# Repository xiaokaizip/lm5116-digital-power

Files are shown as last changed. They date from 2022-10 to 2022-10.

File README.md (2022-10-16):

### lm5116数控可调电源

- 输入电压：24V的学生电源

- 目标输出电压：5V-12V
- 目标输出电流：（越大越好）
- 使用0.96寸oled屏显示电压值

### 电路

#### 一、控制器件

- 主要的电压控制器件还是lm5116
- 其中的stm32f103c8t6还是起到辅助的作用。
  - 控制数字电位器的电阻大小
  - 采集电压
  - 接收按键的输入
  - 控制屏幕的显示内容

#### 二、输出电压的调节

- 使用数字电位器调节反馈端的电压，一次来改变输出电压的大小。

#### 三、数据采集

- 使用ADC将电压采集到单片机。
- 再实时数据通过串口传到电脑

#### 四、控制

- 使用按键进行操作。

#### 五、辅助电源

- 使用TD1469将24V的输入降至5V，在使用HX9193将5V的电压降至3.3V个stm32 、数字电位器供电、屏幕供电。

### 代码

#### 一、数字电位器（MCP41100）

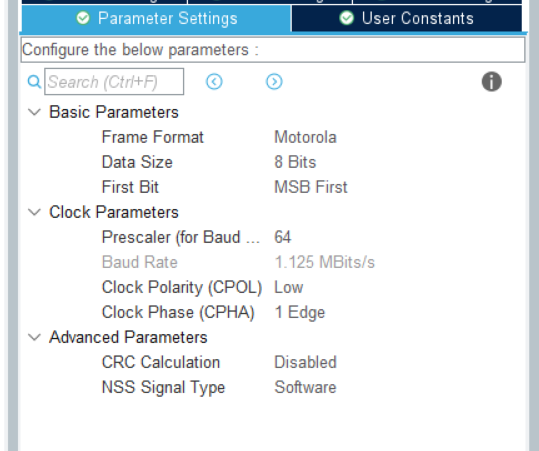
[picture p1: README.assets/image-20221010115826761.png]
- 数字电位器的配置如图所示：

没有用到DMA或是中断，需要的话后续再来给他加上。

- 使能数字电位器

  ~~~c
  #define MCP41100_ENABLE     0B00010011
  #define MCP41100_DISABLE    0B00100000
  ~~~

- 调节数字电位器

  - 数字电位器将100k$\Omega$的电阻分成256份，在使用时，只需将其换算即可。

- 代码

~~~c
uint8_t command;
uint8_t data;

void MCP41100_Send_Data(uint8_t commands, uint8_t datas) {
    HAL_GPIO_WritePin(GPIOA, GPIO_PIN_4, GPIO_PIN_RESET);//来低数字电位器的CS引脚，开始准备通讯
    HAL_Delay(0);
    HAL_SPI_Transmit(&hspi1, &command, 1, 0xffff);//传送命令字节
    HAL_SPI_Transmit(&hspi1, &data, 1, 0xffff);//传送数据字节
    HAL_Delay(0);
    HAL_GPIO_WritePin(GPIOA, GPIO_PIN_4, GPIO_PIN_SET);//将CS引脚拉高，关闭通讯
}

~~~

==相应的文件以放在divice-library文件夹中==

#### 二、延时函数

==相应的文件以放在divice-library文件夹中==

#### 三、OLED屏

- 在此次的项目中，使用了软件iic。

- 其中OLED屏的驱动也是从别处搬来的，后续咋来研究是怎么写的。

- 相关的函数说明

~~~c
 OLED_Init();	//初始化OLED
 OLED_Fill(0x00);//清屏
 OLED_ShowStr(0, 0, "hell world");//在指定位置显示字符串
 OLED_ShowFloat(0,0,123.456f);//在指定的位置显示浮点数（小数点后三位）
~~~

==相应的文件以放在divice-library文件夹中==

#### 四、 数据类型转化

- 将浮点数转化为字符串

~~~c

void numTostring(float num, char str[10]) {

    char ch[10];
    int i = 0;//跟随ch
    int j = 0;//跟随str
    //判断是否是负数
    if (num < 0) {
        num = -num;
        str[j++] = '-';

    }
    //判断是否是小数，如果是小数，先加上0；
    if (num < 1) {
        str[j++] = '0';

    }
    //将小数乘上1000，意味着将该数字精确到小数点后三位，要改精度就改一下1000这个数字就行
    num *= 1000;
    int nums = (int) num;//将小数转换为整数
    for (i = 8; i >= 0; i--) {
        if (i == 5) {
            ch[i] = '.';
            i--;
        }
        ch[i] = nums % 10 + '0';
        nums /= 10;
    }
    //加上小数点
    ch[9] = '\0';
    i = 0;
    while (ch[i] == '0') {
        i++;
    }
    for (i; i <= 9; i++) {
        str[j] = ch[i];
        j++;
    }
}
~~~

==相应的文件以放在divice-library文件夹中==

- 该转换方式还是有点过于复杂，后续还需学习更加方便的转换方法。

#### 五、ADC电压采样

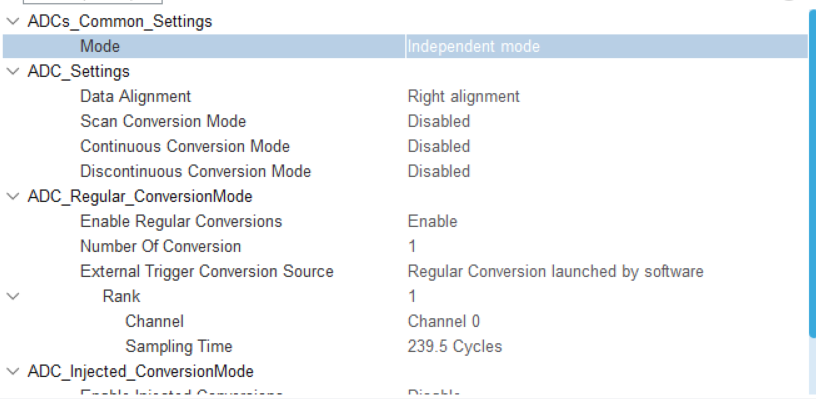
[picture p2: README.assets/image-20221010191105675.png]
- ADC的简单配置如下：
  - **Data Alignment**：选则有对齐
  - **Scan Conversion Mode：**此项选择扫描模式使能，代表15路ADC输入分别扫描，如果不使能，其只会读取一个输入的值。
  - **Contionous Conversion Mode:**此项选择连续扫描模式，表示将连续不断的对ADC的值进行转换，如果此项不使能，将会只采集一次就停止，直到下一次使能才继续进行一次AD转换。
  - **DisContionous Conversion Mode:**此项与第三项重复。
  - **Number of Conversion：**此处有多少路输出就选择多少。
  - **Rank：**采样时间。
- DMA的配置

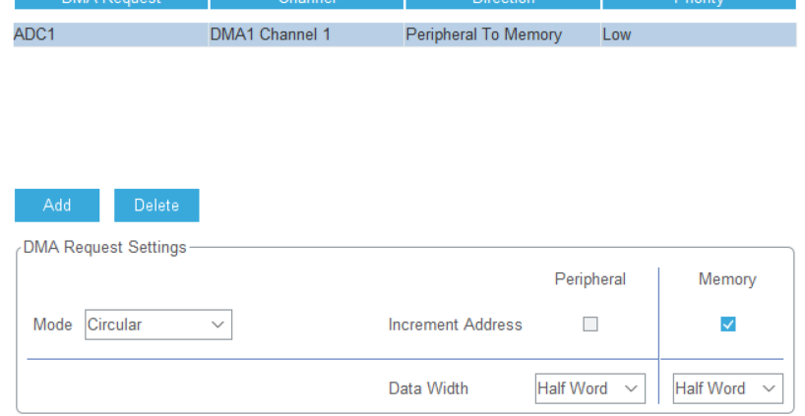
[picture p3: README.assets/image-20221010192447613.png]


- 代码

~~~c
HAL_ADC_Start_DMA(&hadc1, (uint32_t *) adc_value, 1);
//使能DMA，adc_value 为存储数据的数组，1为每一次采样的次数（该数组的大小）
~~~

~~~c
HAL_ADC_Stop_DMA(&hadc1);//失能DMA
~~~

- ADC采样时，如果想要同时采集多个电压，需要打开中断，然后再ADC中断函数中处理数据。

~~~c
void HAL_ADC_ConvCpltCallback();
~~~

可在此函数中，对采集到的电压进行数据处理。

~~~c
void HAL_ADC_ConvCpltCallback(ADC_HandleTypeDef *hadc) {
    uint32_t sum = 0;
    for (uint8_t i = 0; i < 40; i++) {
        sum += adc_value[i];
    }
    avgerage_voltage = (float) sum / 40.0f;
    avgerage_voltage = avgerage_voltage * 0.2f + last_voltage * 0.8f;
    last_voltage = avgerage_voltage;
    flag = 1;
}
~~~

#### 六、按键处理

- 消抖

~~~c
if (HAL_GPIO_ReadPin(GPIOB, GPIO_PIN_12) == GPIO_PIN_RESET) {
        HAL_Delay(10);
        while (HAL_GPIO_ReadPin(GPIOB, GPIO_PIN_12) == GPIO_PIN_RESET);
        HAL_Delay(10);
        flag = RESISTANCE_UP;
    } 
~~~

### 问题

- 该板子是一个可调压的buck电路，输入电压为24V，输出电压为5V至12V
- 可通过stm32f103c6t6，控制数字电位器，以此来控制输出电压。

- 该板子函数有一点问题
 - 按键的设置没设置好。
 - 比如lm5116发烫有点严重，可能是参数还没调好。
 - 采样的滤波还没写好。
 - ……

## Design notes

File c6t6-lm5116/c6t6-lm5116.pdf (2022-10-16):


10/10/2022

c6t6-lm5116 Project
Configuration Report

## 1. Description

### 1.1. Project

Project Name | c6t6-lm5116
Board Name | custom
Generated with: | STM32CubeMX 6.6.1
Date | 10/10/2022

### 1.2. MCU

MCU Series | STM32F1
MCU Line | STM32F103
MCU name | STM32F103C6Tx
MCU Package | LQFP48
MCU Pin number | 48

### 1.3. Core(s) information

Core(s) | Arm Cortex-M3

## 2. Pinout Configuration

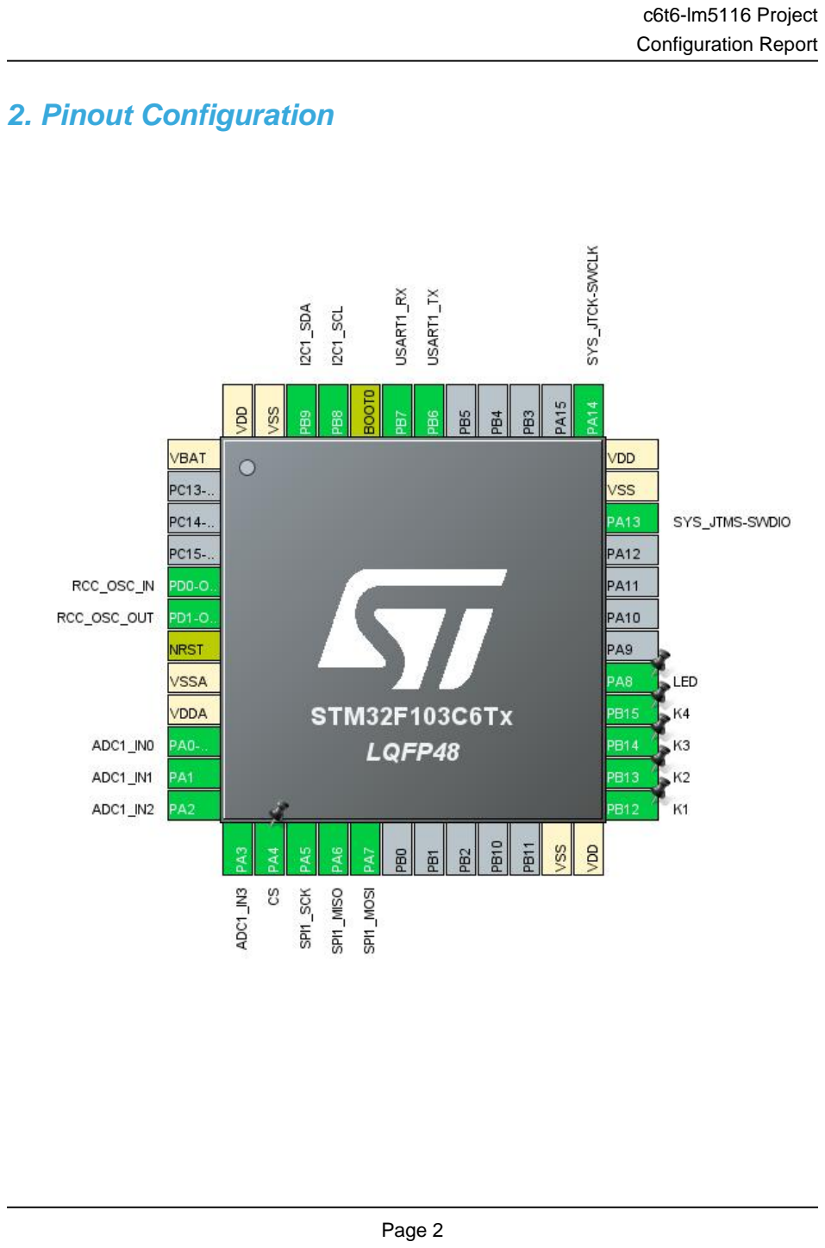
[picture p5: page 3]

## 3. Pins Configuration

Pin Number LQFP48 | Pin Name (function after reset) | Pin Type | Alternate Function(s) | Label
1 | VBAT | Power
5 | PD0-OSC_IN | I/O | RCC_OSC_IN
6 | PD1-OSC_OUT | I/O | RCC_OSC_OUT
7 | NRST | Reset
8 | VSSA | Power
9 | VDDA | Power
10 | PA0-WKUP | I/O | ADC1_IN0
11 | PA1 | I/O | ADC1_IN1
12 | PA2 | I/O | ADC1_IN2
13 | PA3 | I/O | ADC1_IN3
14 | PA4 * | I/O | GPIO_Output | CS
15 | PA5 | I/O | SPI1_SCK
16 | PA6 | I/O | SPI1_MISO
17 | PA7 | I/O | SPI1_MOSI
23 | VSS | Power
24 | VDD | Power
25 | PB12 * | I/O | GPIO_Input | K1
26 | PB13 * | I/O | GPIO_Input | K2
27 | PB14 * | I/O | GPIO_Input | K3
28 | PB15 * | I/O | GPIO_Input | K4
29 | PA8 * | I/O | GPIO_Output | LED
34 | PA13 | I/O | SYS_JTMS-SWDIO
35 | VSS | Power
36 | VDD | Power
37 | PA14 | I/O | SYS_JTCK-SWCLK
42 | PB6 | I/O | USART1_TX
43 | PB7 | I/O | USART1_RX
44 | BOOT0 | Boot
45 | PB8 | I/O | I2C1_SCL
46 | PB9 | I/O | I2C1_SDA
47 | VSS | Power
48 | VDD | Power

* The pin is affected with an I/O function

## 4. Clock Tree Configuration

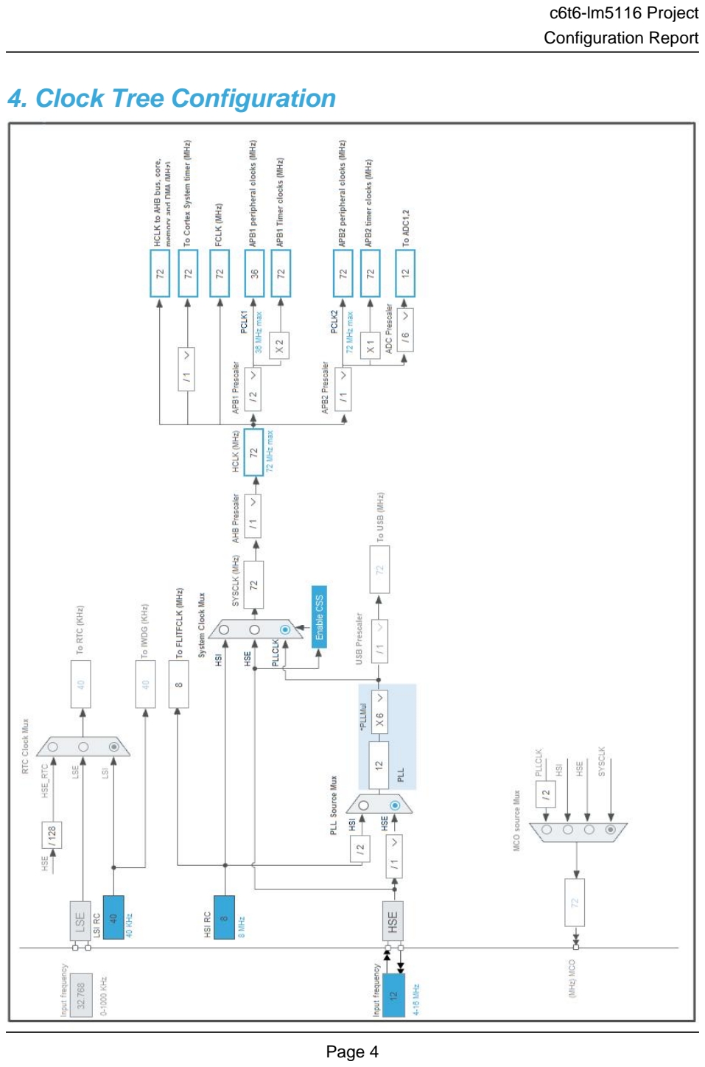
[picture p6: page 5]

## 5. Software Project

### 5.1. Project Settings

Name | Value
Project Name | c6t6-lm5116
Project Folder | D:\stm32 project\c6t6-lm5116
Toolchain / IDE | STM32CubeIDE
Firmware Package Name and Version | STM32Cube FW_F1 V1.8.4
Application Structure | Advanced
Generate Under Root | Yes
Do not generate the main() | No
Minimum Heap Size | 0x200
Minimum Stack Size | 0x400

### 5.2. Code Generation Settings

Name | Value
STM32Cube MCU packages and embedded software | Copy only the necessary library files
Generate peripheral initialization as a pair of '.c/.h' files | Yes
Backup previously generated files when re-generating | No
Keep User Code when re-generating | Yes
Delete previously generated files when not re-generated | Yes
Set all free pins as analog (to optimize the power consumption) | No
Enable Full Assert | No

### 5.3. Advanced Settings - Generated Function Calls

Rank | Function Name | Peripheral Instance Name
1 | SystemClock_Config | RCC
2 | MX_GPIO_Init | GPIO
3 | MX_ADC1_Init | ADC1
4 | MX_I2C1_Init | I2C1
5 | MX_SPI1_Init | SPI1
6 | MX_USART1_UART_Init | USART1

## 6. Power Consumption Calculator report

### 6.1. Microcontroller Selection

Series | STM32F1
Line | STM32F103
MCU | STM32F103C6Tx
Datasheet | DS5936_Rev7

### 6.2. Parameter Selection

Temperature | 25
Vdd | 3.3

### 6.3. Battery Selection

Battery | Li-SOCL2(A3400)
Capacity | 3400.0 mAh
Self Discharge | 0.08 %/month
Nominal Voltage | 3.6 V
Max Cont Current | 100.0 mA
Max Pulse Current | 200.0 mA
Cells in series | 1
Cells in parallel | 1

### 6.4. Sequence

Step | Step1 | Step2
Mode | RUN | STOP
Vdd | 3.3 | 3.3
Voltage Source | Battery | Battery
Range | No Scale | No Scale
Fetch Type | FLASH | n/a
CPU Frequency | 72 MHz | 0 Hz
Clock Configuration | HSE PLL | Regulator_LP
Clock Source Frequency | 8 MHz | 0 Hz
Peripherals
Additional Cons. | 0 mA | 0 mA
Average Current | 24.5 mA | 11.7 µA
Duration | 0.1 ms | 0.9 ms
DMIPS | 90.0 | 0.0
Ta Max | 100.55 | 105
Category | In DS Table | In DS Table

### 6.5. Results

Sequence Time | 1 ms | Average Current | 2.46 mA
Battery Life | 1 month, 27 days, 1 hour | Average DMIPS | 61.0 DMIPS

### 6.6. Chart

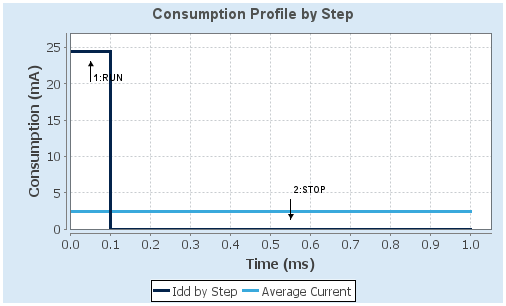
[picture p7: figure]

## 7. Peripherals and Middlewares Configuration

### 7.1. ADC1

mode: IN0
mode: IN1
mode: IN2
mode: IN3
7.1.1. Parameter Settings:

ADCs_Common_Settings:

Mode | Independent mode
ADC_Settings:
Data Alignment | Right alignment
Scan Conversion Mode | Disabled
Continuous Conversion Mode | Disabled
Discontinuous Conversion Mode | Disabled
ADC_Regular_ConversionMode:
Enable Regular Conversions | Enable
Number Of Conversion | 1
External Trigger Conversion Source | Regular Conversion launched by software
Rank | 1
Channel | Channel 0
Sampling Time | 1.5 Cycles
ADC_Injected_ConversionMode:
Enable Injected Conversions | Disable
WatchDog:
Enable Analog WatchDog Mode | false

### 7.2. I2C1

I2C: I2C
7.2.1. Parameter Settings:

Master Features:

I2C Speed Mode | Standard Mode
I2C Clock Speed (Hz) | 100000
Slave Features:
Clock No Stretch Mode | Disabled
Primary Address Length selection | 7-bit

Dual Address Acknowledged | Disabled
Primary slave address | 0
General Call address detection | Disabled

### 7.3. RCC

High Speed Clock (HSE): Crystal/Ceramic Resonator
7.3.1. Parameter Settings:

System Parameters:

VDD voltage (V) | 3.3
Prefetch Buffer | Enabled
Flash Latency(WS) | 2 WS (3 CPU cycle)
RCC Parameters:
HSI Calibration Value | 16
HSE Startup Timout Value (ms) | 100
LSE Startup Timout Value (ms) | 5000

### 7.4. SPI1

Mode: Full-Duplex Master
7.4.1. Parameter Settings:

Basic Parameters:

Frame Format | Motorola
Data Size | 8 Bits
First Bit | MSB First
Clock Parameters:
Prescaler (for Baud Rate) | 64 *
Baud Rate | 1.125 MBits/s *
Clock Polarity (CPOL) | Low
Clock Phase (CPHA) | 1 Edge
Advanced Parameters:
CRC Calculation | Disabled
NSS Signal Type | Software

### 7.5. SYS

Debug: Serial Wire
Timebase Source: SysTick

### 7.6. USART1

Mode: Asynchronous
7.6.1. Parameter Settings:

Basic Parameters:

Baud Rate | 115200
Word Length | 8 Bits (including Parity)
Parity | None
Stop Bits | 1
Advanced Parameters:
Data Direction | Receive and Transmit
Over Sampling | 16 Samples

* User modified value

## 8. System Configuration

### 8.1. GPIO configuration

IP | Pin | Signal | GPIO mode | GPIO pull/up pull down | Max Speed | User Label
ADC1 | PA0-WKUP | ADC1_IN0 | Analog mode | n/a | n/a
| PA1 | ADC1_IN1 | Analog mode | n/a | n/a
| PA2 | ADC1_IN2 | Analog mode | n/a | n/a
| PA3 | ADC1_IN3 | Analog mode | n/a | n/a
I2C1 | PB8 | I2C1_SCL | Alternate Function Open Drain | No pull-up and no pull-down | n/a
| PB9 | I2C1_SDA | Alternate Function Open Drain | No pull-up and no pull-down | n/a
RCC | PD0-OSC_IN | RCC_OSC_IN | n/a | n/a | n/a
| PD1-OSC_OUT | RCC_OSC_OUT | n/a | n/a | n/a
SPI1 | PA5 | SPI1_SCK | Alternate Function Push Pull | n/a | High *
| PA6 | SPI1_MISO | Input mode | No pull-up and no pull-down | n/a
| PA7 | SPI1_MOSI | Alternate Function Push Pull | n/a | High *
SYS | PA13 | SYS_JTMS-SWDIO | n/a | n/a | n/a
| PA14 | SYS_JTCK-SWCLK | n/a | n/a | n/a
USART1 | PB6 | USART1_TX | Alternate Function Push Pull | n/a | High *
| PB7 | USART1_RX | Input mode | No pull-up and no pull-down | n/a
GPIO | PA4 | GPIO_Output | Output Push Pull | No pull-up and no pull-down | Low | CS
| PB12 | GPIO_Input | Input mode | No pull-up and no pull-down | n/a | K1
| PB13 | GPIO_Input | Input mode | No pull-up and no pull-down | n/a | K2
| PB14 | GPIO_Input | Input mode | No pull-up and no pull-down | n/a | K3
| PB15 | GPIO_Input | Input mode | No pull-up and no pull-down | n/a | K4
| PA8 | GPIO_Output | Output Push Pull | No pull-up and no pull-down | Low | LED

### 8.2. DMA configuration

nothing configured in DMA service

### 8.3. NVIC configuration

8.3.1. NVIC
Interrupt Table | Enable | Preenmption Priority | SubPriority
Non maskable interrupt | true | 0 | 0
Hard fault interrupt | true | 0 | 0
Memory management fault | true | 0 | 0
Prefetch fault, memory access fault | true | 0 | 0
Undefined instruction or illegal state | true | 0 | 0
System service call via SWI instruction | true | 0 | 0
Debug monitor | true | 0 | 0
Pendable request for system service | true | 0 | 0
System tick timer | true | 15 | 0
PVD interrupt through EXTI line 16 | unused
Flash global interrupt | unused
RCC global interrupt | unused
ADC1 and ADC2 global interrupts | unused
I2C1 event interrupt | unused
I2C1 error interrupt | unused
SPI1 global interrupt | unused
USART1 global interrupt | unused
8.3.2. NVIC Code generation
Enabled interrupt Table | Select for init sequence ordering | Generate IRQ handler | Call HAL handler
Non maskable interrupt | false | true | false
Hard fault interrupt | false | true | false
Memory management fault | false | true | false
Prefetch fault, memory access fault | false | true | false
Undefined instruction or illegal state | false | true | false
System service call via SWI instruction | false | true | false
Debug monitor | false | true | false
Pendable request for system service | false | true | false
System tick timer | false | true | true

* User modified value

## 9. System Views

9.1. Category view
9.1.1. Current

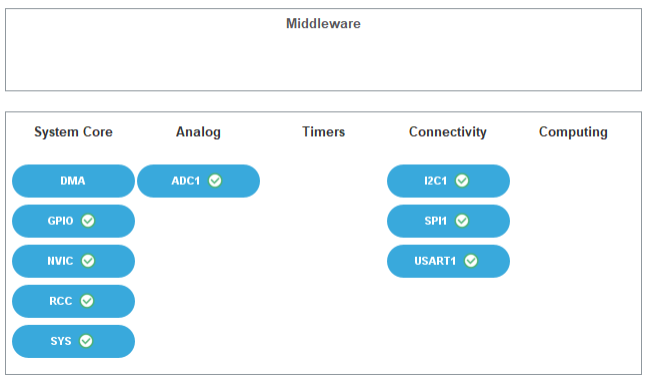
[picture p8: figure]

## 10. Docs & Resources

Type | Link
Presentations | https://www.st.com/resource/en/product_presentation/stm32-stm8_embedded_software_solutions.pdf
Presentations | https://www.st.com/resource/en/product_presentation/stm32_eval-tools_portfolio.pdf
Presentations | https://www.st.com/resource/en/product_presentation/stm32_stm8_functi onal-safety-packages.pdf
Presentations | https://www.st.com/resource/en/product_presentation/stm32-stm8_software_development_tools.pdf
Training Material | https://www.st.com/resource/en/sales_guide/sg_sc2155.pdf
Brochures | https://www.st.com/resource/en/brochure/breveco0518.pdf
Flyers | https://www.st.com/resource/en/flyer/flnucleolrwan.pdf
Flyers | https://www.st.com/resource/en/flyer/flstm32nucleo.pdf
Flyers | https://www.st.com/resource/en/flyer/flstmcsuite.pdf
Flyers | https://www.st.com/resource/en/flyer/fldpstpfc11120.pdf
Product Certifications | https://www.st.com/resource/en/certification_document/1239988349.pdf
Product Certifications | https://www.st.com/resource/en/certification_document/stm32_authentication_can.pdf
Application Notes | https://www.st.com/resource/en/application_note/an1181-electrostatic-discharge-sensitivity-measurement-stmicroelectronics.pdf
Application Notes | https://www.st.com/resource/en/application_note/an1709-emc-design-guide-for-stm8-stm32-and-legacy-mcus-stmicroelectronics.pdf
Application Notes | https://www.st.com/resource/en/application_note/an2548-using-the-stm32f0f1f3gxlx-series-dma-controller-stmicroelectronics.pdf
Application Notes | https://www.st.com/resource/en/application_note/an2586-getting-started-with-stm32f10xxx-hardware-development-stmicroelectronics.pdf
Application Notes | https://www.st.com/resource/en/application_note/an2604-stm32f101xx-and-stm32f103xx-rtc-calibration-stmicroelectronics.pdf
Application Notes | https://www.st.com/resource/en/application_note/an2606-stm32-

| microcontroller-system-memory-boot-mode-stmicroelectronics.pdf
Application Notes | https://www.st.com/resource/en/application_note/an2639-soldering-recommendations-and-package-information-for-leadfree-ecopack-mcus-and-mpus-stmicroelectronics.pdf
Application Notes | https://www.st.com/resource/en/application_note/an2834-how-to-get-the-best-adc-accuracy-in-stm32-microcontrollers-stmicroelectronics.pdf
Application Notes | https://www.st.com/resource/en/application_note/an2945-stm8s-and-stm32-mcus-a-consistent-832bit-product-line-for-painless-migration-stmicroelectronics.pdf
Application Notes | https://www.st.com/resource/en/application_note/an3070-managing-the-driver-enable-signal-for-rs485-and-iolink-communications-with-the-stm32s-usart-stmicroelectronics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
Application Notes | https://www.st.com/resource/en/application_note/an3095-stevalisv002v1-stevalisv002v2-3-kw-gridconnected-pv-system-based-on-the-stm32f103xx-stmicroelectronics.pdf
Application Notes | https://www.st.com/resource/en/application_note/an3108-stlm75-firmware-library-for-the-stm32f10x-stmicroelectronics.pdf
Application Notes | https://www.st.com/resource/en/application_note/an3126-audio-and-waveform-generation-using-the-dac-in-stm32-products-stmicroelectronics.pdf
Application Notes | https://www.st.com/resource/en/application_note/an3128-stm32-embedded-graphic-objectstouchscreen-library-stmicroelectronics.pdf
Application Notes | https://www.st.com/resource/en/application_note/an3154-can-protocol-used-in-the-stm32-bootloader-stmicroelectronics.pdf
Application Notes | https://www.st.com/resource/en/application_note/an3155-usart-protocol-used-in-the-stm32-bootloader-stmicroelectronics.pdf
Application Notes | https://www.st.com/resource/en/application_note/an3156-usb-dfu-protocol-used-in-the-stm32-bootloader-stmicroelectronics.pdf
Application Notes | https://www.st.com/resource/en/application_note/an3364-migration-and-compatibility-guidelines-for-stm32-microcontroller-applications-stmicroelectronics.pdf
Application Notes | https://www.st.com/resource/en/application_note/an3422-migration-of- microcontroller-applications-from-stm32f1-to-stm32l1-series-

| stmicroelectronics.pdf
Application Notes | https://www.st.com/resource/en/application_note/an3427-migrating-a-microcontroller-application-from-stm32f1-to-stm32f2-series-stmicroelectronics.pdf
Application Notes | https://www.st.com/resource/en/application_note/an3429-stm32-proprietary-code-protection-overview-stmicroelectronics.pdf
Application Notes | https://www.st.com/resource/en/application_note/an4013-stm32-crossseries-timer-overview-stmicroelectronics.pdf
Application Notes | https://www.st.com/resource/en/application_note/an4070-250-w-grid-connected-microinverter-stmicroelectronics.pdf
Application Notes | https://www.st.com/resource/en/application_note/an4076-two-or-three-shunt-resistor-based-current-sensing-circuit-design-in-3phase-inverters-stmicroelectronics.pdf
Application Notes | https://www.st.com/resource/en/application_note/an4088-migrating-between-stm32f1-and-stm32f0-series-microcontrollers-stmicroelectronics.pdf
Application Notes | https://www.st.com/resource/en/application_note/an4228-migrating-from-stm32f1-series-to-stm32f3-series-microcontrollers-stmicroelectronics.pdf
Application Notes | https://www.st.com/resource/en/application_note/an4229-how-to-implement-a-vocoder-solution-using-stm32-microcontrollers-stmicroelectronics.pdf
Application Notes | https://www.st.com/resource/en/application_note/an4277-using-stm32-device-pwm-shutdown-features-for-motor-control-and-digital-power-conversion-stmicroelectronics.pdf
Application Notes | https://www.st.com/resource/en/application_note/an4566-extending-the-dac-performance-of-stm32-microcontrollers-stmicroelectronics.pdf
Application Notes | https://www.st.com/resource/en/application_note/an4649-migrating-from-stm32f1-series-to-stm32l4-series--stm32l4-series-microntrollers-stmicroelectronics.pdf
Application Notes | https://www.st.com/resource/en/application_note/an4655-virtually-increasing-the-number-of-serial-communication-peripherals-in-stm32-applications-stmicroelectronics.p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
Application Notes | https://www.st.com/resource/en/application_note/an4724-stm32cube-

| firmware-examples-for-stm32f1-series-stmicroelectronics.pdf
Application Notes | https://www.st.com/resource/en/application_note/an4750-handling-of-soft-errors-in-stm32-applications-stmicroelectronics.pdf
Application Notes | https://www.st.com/resource/en/application_note/an4776-generalpurpose-timer-cookbook-for-stm32-microcontrollers-stmicroelectronics.pdf
Application Notes | https://www.st.com/resource/en/application_note/an4803-highspeed-si-simulations-using-ibis-and-boardlevel-simulations-using-hyperlynx-si-on-stm32-mcus-and-mpus-stmic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
Application Notes | https://www.st.com/resource/en/application_note/an4838-managing-memory-protection-unit-in-stm32-mcus-stmicroelectronics.pdf
Application Notes | https://www.st.com/resource/en/application_note/an4879-usb-hardware-and-pcb-guidelines-using-stm32-mcus-stmicroelectronics.pdf
Application Notes | https://www.st.com/resource/en/application_note/an4904-migration-of-microcontroller-applications-from-stm32f1-series-to-stm32f4-access-lines-stmicroelectronics.pdf
Application Notes | https://www.st.com/resource/en/application_note/an4908-stm32-usart-automatic-baud-rate-detection-stmicroelectronics.pdf
Application Notes | https://www.st.com/resource/en/application_note/an4989-stm32-microcontroller-debug-toolbox-stmicroelectronics.pdf
Application Notes | https://www.st.com/resource/en/application_note/an5027-interfacing-pdm-digital-microphones-using-stm32-mcus-and-mpus-stmicroelectronics.pdf
Application Notes | https://www.st.com/resource/en/application_note/an5036-thermal-management-guidelines-for-stm32-applications-stmicroelectronics.pdf
Application Notes | https://www.st.com/resource/en/application_note/an5156-introduction-to-stm32-microcontrollers-security-stmicroelectronics.pdf
Application Notes | https://www.st.com/resource/en/application_note/an5225-usb-typec-power-delivery-using-stm32-mcus-and-mpus-stmicroelectronics.pdf
Application Notes | https://www.st.com/resource/en/application_note/an5543-enhanced-methods-to-handle-spi-communication-on-stm32-devices-stmicroelectronics.pdf
Application Notes | https://www.st.com/resource/en/application_note/an4899-stm32-microcontroller-gpio-hardware-settings-and-lowpower-consumption-stmicroelectronics.pdf

Application Notes for related Tools & Software | https://www.st.com/resource/en/application_note/an1202_freertos_guide-freertos-guide-stmicroelectronics.pdf
Application Notes for related Tools & Software | https://www.st.com/resource/en/application_note/an1602_semihosting_in_truestudio-how-to-do-semihosting-in-truestudio-stmicroelectronics.pdf
Application Notes for related Tools & Software | https://www.st.com/resource/en/application_note/an1801_stm32cubeprogrammer_in_truestudio-installing-stm32cubeprogrammer-in-truestudio-stmicroelectronics.pdf
Application Notes for related Tools & Software | https://www.st.com/resource/en/application_note/atollic_editing_keyboard_shortcuts-atollic-editing-keyboard-shortcuts-stmicroelectronics.pdf
Application Notes for related Tools & Software | https://www.st.com/resource/en/application_note/iar_to_atollic_truestudio_migration_guide-truestudio-for-arm-migration-guide-iar-embedded-workbench-to-truestudio-stm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
Application Notes for related Tools & Software | https://www.st.com/resource/en/application_note/stm32cubemx_installation_in_truestudio-stm32cubemx-installation-in-truestudio-stmicroelectronics.pdf
Application Notes for related Tools & Software | https://www.st.com/resource/en/application_note/an2557-stm32f10x-inapplication-programming-using-the-usart-stmicroelectronics.pdf
Application Notes for related Tools & Software | https://www.st.com/resource/en/application_note/an2592-achieving-32bit-timer-resolution-with-software-expansion-for-stm32cube-and-standard-peripheral-library-stmicro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
Application Notes for related Tools & Software | https://www.st.com/resource/en/application_note/an2594-eeprom-emulation-in-stm32f10x-microcontrollers-stmicroelectronics.pdf
Application Notes for related Tools & Software | https://www.st.com/resource/en/application_note/an2598-smartcard-interface-with-stm32f10x-and-stm32l1xx-microcontrollers-stmicroelectronics.pdf
Application Notes for related Tools & Software | https://www.st.com/resource/en/application_note/an2629-stm32f101xx-stm32f102xx-and-stm32f103xx-lowpower-modes-stmicroelectronics.pdf
Application Notes | https://www.st.com/resource/en/application_note/an2656-stm32f10xxx-

for related Tools & Software | lcd-glass-driver-firmware-stmicroelectronics.pdf
Application Notes for related Tools & Software | https://www.st.com/resource/en/application_note/an2668-improving-stm32f1-series-stm32f3-series-and-stm32lx-series-adc-resolution-by-oversampling-stmicroelectronics.p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
Application Notes for related Tools & Software | https://www.st.com/resource/en/application_note/an2739-how-to-use-the-highdensity-stm32f103xx-microcontroller-to-play-audio-files-with-an-external-is-audio-codec-stm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
Application Notes for related Tools & Software | https://www.st.com/resource/en/application_note/an2784-using-the-highdensity-stm32f10xxx-fsmc-peripheral-to-drive-external-memories-stmicroelectronics.pdf
Application Notes for related Tools & Software | https://www.st.com/resource/en/application_note/an2790-tft-lcd-interfacing-with-the-highdensity-stm32f10xxx-fsmc-stmicroelectronics.pdf
Application Notes for related Tools & Software | https://www.st.com/resource/en/application_note/an2820-driving-bipolar-stepper-motors-using-a-mediumdensity-stm32f103xx-microcontroller-stmicroelectronics.pdf
Application Notes for related Tools & Software | https://www.st.com/resource/en/application_note/an2821-clockcalendar-implementation-on-the-stm32f10xxx-microcontroller-rtc-stmicroelectronics.pdf
Application Notes for related Tools & Software | https://www.st.com/resource/en/application_note/an2824-stm32f10xxx-ic-optimized-examples-stmicroelectronics.pdf
Application Notes for related Tools & Software | https://www.st.com/resource/en/application_note/an2841-led-dimming-implemented-on-stm32-microcontroller-stmicroelectronics.pdf
Application Notes for related Tools & Software | https://www.st.com/resource/en/application_note/an2868-stm32f10xxx-internal-rc-oscillator-hsi-calibration-stmicroelectronics.pdf
Application Notes for related Tools & Software | https://www.st.com/resource/en/application_note/an2931-implementing-the-adpcm-algorithm-in-highdensity-stm32f103xx-microcontrollers-stmicroelectronics.pdf

Application Notes
for related Tools

https://www.st.com/resource/en/application_note/an2953-how-to-migratefrom-the-stm32f10xxx-firmware-library-v203-to-the-stm32f10xxx-standard-

& Software | peripheral-library-v300-stmicroelectronics.pdf
Application Notes for related Tools & Software | https://www.st.com/resource/en/application_note/an3012-getting-started-with-uclinux-for-stm32f10x-highdensity-devices-stmicroelectronics.pdf
Application Notes for related Tools & Software | https://www.st.com/resource/en/application_note/an3078-stm32-inapplication-programming-over-the-ic-bus-stmicroelectronics.pdf
Application Notes for related Tools & Software | https://www.st.com/resource/en/application_note/an3109-communication-peripheral-fifo-emulation-with-dma-and-dma-timeout-in-stm32f10x-microcontrollers-stmicroelectron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
Application Notes for related Tools & Software | https://www.st.com/resource/en/application_note/an3116-stm32s-adc-modes-and-their-applications-stmicroelectronics.pdf
Application Notes for related Tools & Software | https://www.st.com/resource/en/application_note/an3174-implementing-receivers-for-infrared-remote-control-protocols-using-stm32f10xxx-microcontrollers-stmicroelectro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
Application Notes for related Tools & Software | https://www.st.com/resource/en/application_note/an3240-ultrasound-hv-pulser-demonstration-board-stmicroelectronics.pdf
Application Notes for related Tools & Software | https://www.st.com/resource/en/application_note/an3241-qvga-tftlcd-direct-drive-using-the-stm32f10xx-fsmc-peripheral-stmicroelectronics.pdf
Application Notes for related Tools & Software | https://www.st.com/resource/en/application_note/an3307-guidelines-for-obtaining-iec-60335-class-b-certification-for-any-stm32-application-stmicroelectronics.pdf
Application Notes for related Tools & Software | https://www.st.com/resource/en/application_note/an3970-plm-smartplug-v2-getting-started-stmicroelectronics.pdf
Application Notes for related Tools & Software | https://www.st.com/resource/en/application_note/an3991-how-to-drive-multiple-stepper-motors-with-the-l6470-motor-driver-stmicroelectronics.pdf
Application Notes for related Tools & Software | https://www.st.com/resource/en/application_note/an4075-stevalifp016v2-iolink-communication-master-transceiver-demonstration-board-stmicroelectronics.pdf

Application Notes for related Tools & Software | https://www.st.com/resource/en/application_note/an4187-using-the-crc-peripheral-in-the-stm32-family-stmicroelectronics.pdf
Application Notes for related Tools & Software | https://www.st.com/resource/en/application_note/an4323-getting-started-with-stemwin-library-stmicroelectronics.pdf
Application Notes for related Tools & Software | https://www.st.com/resource/en/application_note/an4435-guidelines-for-obtaining-ulcsaiec-607301603351-class-b-certification-in-any-stm32-application-stmicroelectroni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
Application Notes for related Tools & Software | https://www.st.com/resource/en/application_note/an4453-implementing-the-adpcm-algorithm-in-stm32l1xx-microcontrollers-stmicroelectronics.pdf
Application Notes for related Tools & Software | https://www.st.com/resource/en/application_note/an4499-stm32--nrf51822-bluetooth-low-energy-system-solution-stmicroelectronics.pdf
Application Notes for related Tools & Software | https://www.st.com/resource/en/application_note/an4502-stm32-smbuspmbus-embedded-software-expansion-for-stm32cube-stmicroelectronics.pdf
Application Notes for related Tools & Software | https://www.st.com/resource/en/application_note/an4578-16channels-led-driver-with-independent-pwm-dimming-control-based-on-led7708-stmicroelectronics.pdf
Application Notes for related Tools & Software | https://www.st.com/resource/en/application_note/an4657-stm32-inapplication-programming-iap-using-the-usart-stmicroelectronics.pdf
Application Notes for related Tools & Software | https://www.st.com/resource/en/application_note/an4724-stm32cube-firmware-examples-for-stm32f1-series-stmicroelectronics.pdf
Application Notes for related Tools & Software | https://www.st.com/resource/en/application_note/an4841-digital-signal-processing-for-stm32-microcontrollers-using-cmsis-stmicroelectronics.pdf
Application Notes for related Tools & Software | https://www.st.com/resource/en/application_note/an5054-secure-programming-using-stm32cubeprogrammer-stmicroelectronics.pdf
Application Notes | https://www.st.com/resource/en/application_note/an5360-getting-started-

for related Tools & Software | with-projects-based-on-the-stm32mp1-series-in-stm32cubeide-stmicroelectronics.pdf
Application Notes for related Tools & Software | https://www.st.com/resource/en/application_note/an5361-getting-started-with-projects-based-on-dualcore-stm32h7-microcontrollers-in-stm32cubeide-stmicroelectronics.pd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
Application Notes for related Tools & Software | https://www.st.com/resource/en/application_note/an5394-getting-started-with-projects-based-on-the-stm32l5-series-in-stm32cubeide-stmicroelectronics.pdf
Application Notes for related Tools & Software | https://www.st.com/resource/en/application_note/an5418-how-to-build-a-simple-usbpd-sink-application-with-stm32cubemx-stmicroelectronics.pdf
Application Notes for related Tools & Software | https://www.st.com/resource/en/application_note/an5426-migrating-graphics-middleware-projects-from-stm32cubemx-540-to-stm32cubemx-550-stmicroelectronics.pdf
Application Notes for related Tools & Software | https://www.st.com/resource/en/application_note/an5564-getting-started-with-projects-based-on-dualcore-stm32wl-microcontrollers-in-stm32cubeide-stmicroelectronics.pd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
Application Notes for related Tools & Software | https://www.st.com/resource/en/application_note/an5698-adapting-the-xcubestl-functional-safety-package-for-stm32-iec-61508-compliant-to-other-safety-standards-stmicr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
Application Notes for related Tools & Software | https://www.st.com/resource/en/application_note/an5731-stm32cubemx-and-stm32cubeide-threadsafe-solution-stmicroelectronics.pdf
Device Option Lists | https://www.st.com/resource/en/device_option_list/opl_stm32f103_32k.zip
Errata Sheets | https://www.st.com/resource/en/errata_sheet/es0348-stm32f101x46-stm32f102x46-and-stm32f103x46-lowdensity-device-limitations-stmicroelectronics.pdf
Datasheet | https://www.st.com/resource/en/datasheet/cd00210843.pdf
Programming Manuals | https://www.st.com/resource/en/programming_manual/pm0056-stm32f10xxx20xxx21xxxl1xxxx-cortexm3-programming-manual-stmicroelectronics.pdf
Programming Manuals | https://www.st.com/resource/en/programming_manual/pm0075-stm32f10xxx-flash-memory-microcontrollers-stmicroelectronics.pdf

Reference Manuals | https://www.st.com/resource/en/reference_manual/rm0008-stm32f101xx-stm32f102xx-stm32f103xx-stm32f105xx-and-stm32f107xx-advanced-armbased-32bit-mcus-stmicroelectronic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
Technical Notes & Articles | https://www.st.com/resource/en/technical_note/tn0516-overview-of-the-stm32f0xf100xxf103xx-and-stm32f2xxf30xf4xx-mcus-pmsm-singledual-foc-sdk-v40-stmicroelectronics.p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
Technical Notes & Articles | https://www.st.com/resource/en/technical_note/tn1163-description-of-wlcsp-for-microcontrollers-and-recommendations-for-its-use-stmicroelectronics.pdf
Technical Notes & Articles | https://www.st.com/resource/en/technical_note/tn1204-tape-and-reel-shipping-media-for-stm32-microcontrollers-in-bga-packages-stmicroelectronics.pdf
Technical Notes & Articles | https://www.st.com/resource/en/technical_note/tn1205-tape-and-reel-shipping-media-for-stm8-and-stm32-microcontrollers-in-fpn-packages-stmicroelectronics.pdf
Technical Notes & Articles | https://www.st.com/resource/en/technical_note/tn1206-tape-and-reel-shipping-media-for-stm8-and-stm32-microcontrollers-in-qfp-packages-stmicroelectronics.pdf
Technical Notes & Articles | https://www.st.com/resource/en/technical_note/tn1207-tape-and-reel-shipping-media-for-stm8-and-stm32-microcontrollers-in-so-packages-stmicroelectronics.pdf
Technical Notes & Articles | https://www.st.com/resource/en/technical_note/tn1208-tape-and-reel-shipping-media-for-stm8-and-stm32-microcontrollers-in-tssop-and-ssop-packages-stmicroelectronics.p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
User Manuals | https://www.st.com/resource/en/user_manual/um1561-stevalisv003v1-firmware-user-manual-stmicroelectronics.pdf
User Manuals | https://www.st.com/resource/en/user_manual/um1573-st7540-power-line-modem-firmware-stack-stmicroelectronics.pdf

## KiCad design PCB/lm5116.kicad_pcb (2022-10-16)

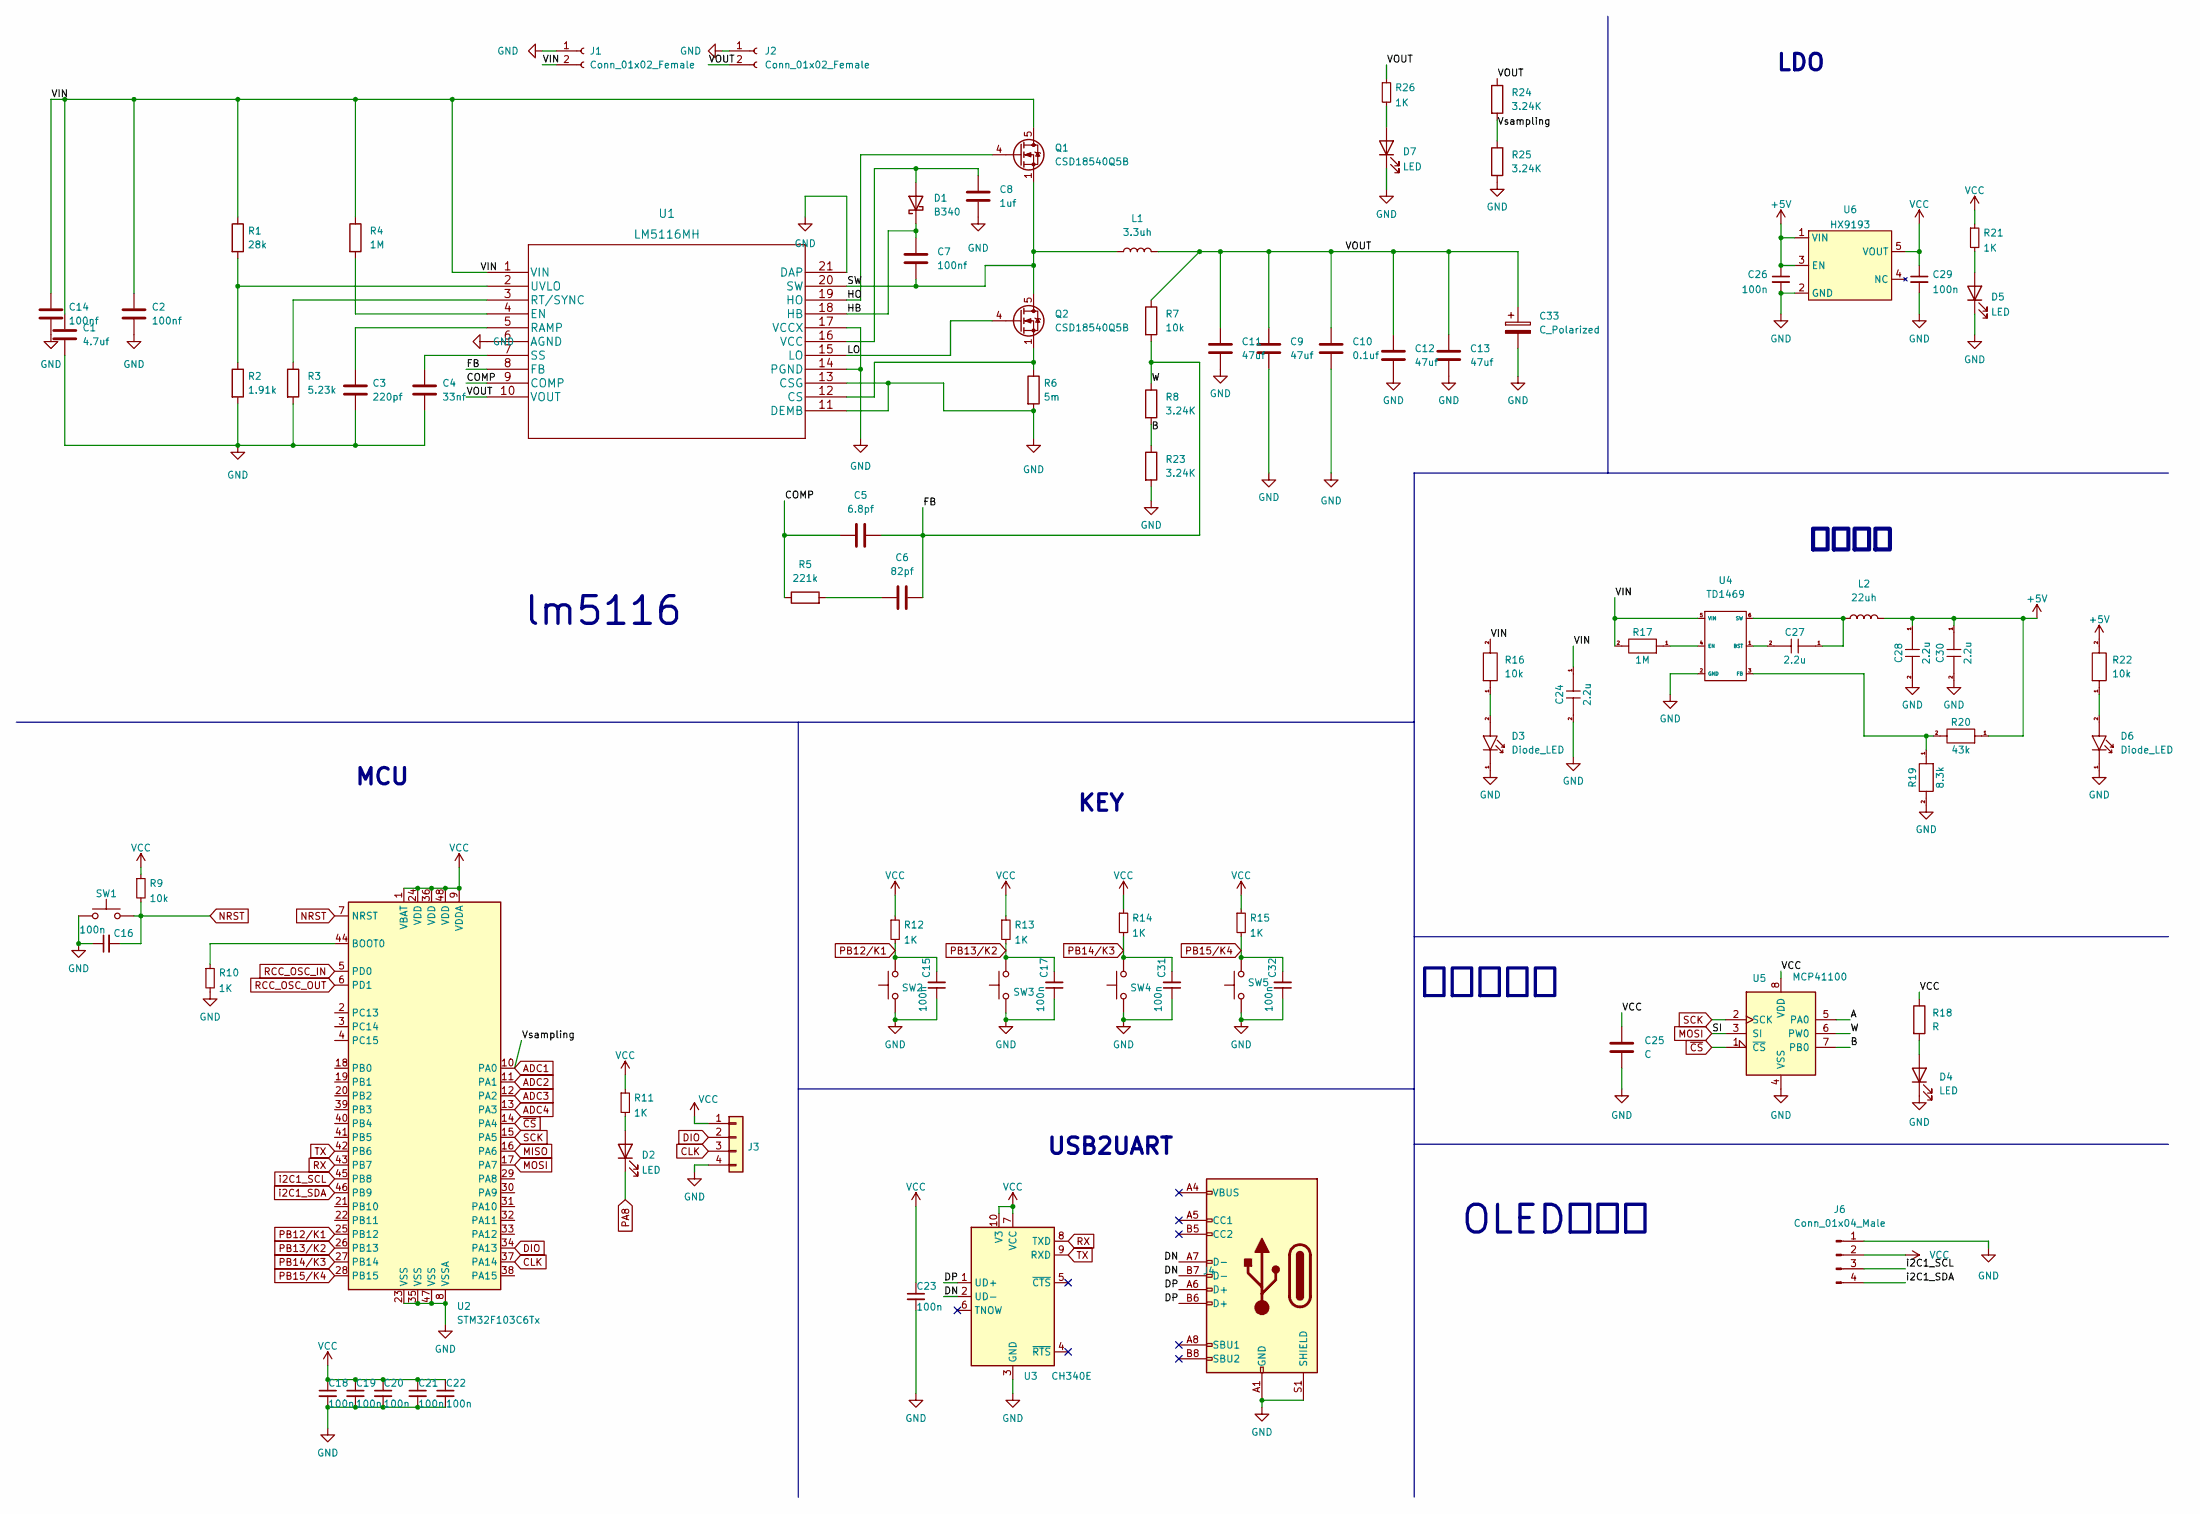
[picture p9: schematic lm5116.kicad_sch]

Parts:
C1: 4.7uf; C_1210_3225Metric
C2, C14: 100nf; C_1210_3225Metric
C3: 220pf; C0603(1608M)
C4: 33nf; C0603(1608M)
C5: 6.8pf; C0603(1608M)
C6: 82pf; C0603(1608M)
C7: 100nf; C0603(1608M)
C8: 1uf; C0603(1608M)
C9, C11, C12, C13: 47uf; C_1210_3225Metric
C10: 0.1uf; C_1210_3225Metric
C15, C16, C17, C18, C19, C20, C21, C22, C23, C26, C29, C31, C32: 100n; C0603(1608M)
C24, C27: 2.2u; C0603(1608M)
C25: C; C0603(1608M)
C28, C30: 2.2u; C1206(3216M)
C33: C_Polarized; CP_Elec_6.3x7.7
D1: B340; D_SMA
D2, D4, D5, D7: LED; LED0603(1608M)
D3, D6: Diode_LED; LED0603(1608M)
J1: Conn_01x02_Female; AMASS_XT30U-M_1x02_P5.0mm_Vertical
J2: Conn_01x02_Female; AMASS_XT30U-F_1x02_P5.0mm_Vertical
J3: Conn_01x04; GH1.25_V_4
J4: USB_C_Receptacle_USB2.0; USB_C_Receptacle_HRO_TYPE-C-31-M-12
J6: Conn_01x04_Male; PinSocket_1x04_P2.54mm_Vertical
L1: 3.3uh; L_Wuerth_HCI-1040
L2: 22uh; L_Abracon_ASPI-0630LR
Q1, Q2: CSD18540Q5B; TDSON-8-1
R1: 28k; R_0603_1608Metric
R2: 1.91k; R_0603_1608Metric
R3: 5.23k; R_0603_1608Metric
R4: 1M; R_0603_1608Metric
R5: 221k; R_0603_1608Metric
R6: 5m; R_2512_6332Metric
R7, R9: 10k; R_0603_1608Metric
R8: 3.24K; R_0603_1608Metric
R10, R11, R12, R13, R14, R15, R21, R26: 1K; R0603(1608M)
R16, R22: 10k; R0603(1608M)
R17: 1M; R0603(1608M)
R18: R; R0603(1608M)
R19: 8.3k; R0603(1608M)
R20: 43k; R0603(1608M)
R23, R24, R25: 3.24K; R0603(1608M)
SW1, SW2, SW3, SW4, SW5: SW_Push; SW_SPST_FSMSM
U1: LM5116MH
U2: STM32F103C6Tx; LQFP-48_7x7mm_P0.5mm
U3: CH340E; MSOP-10_3x3mm_P0.5mm
U4: TD1469; SOT-23-6
U5: MCP41100; SOIC-8_3.9x4.9mm_P1.27mm
U6: HX9193; SOT-23-5_HandSoldering

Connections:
+5V: C26.1, C28.1, C30.1, L2.2, R20.1, R22.2, U6.1 (VIN), U6.3 (EN)
/A: U5.5 (PA0)
/B: R8.2, R23.1, U5.7 (PB0)
/COMP: C5.1, R5.1, U1.9 (COMP)
/DN: J4.A7 (D-), J4.B7 (D-), U3.2 (UD-)
/DP: J4.A6 (D+), J4.B6 (D+), U3.1 (UD+)
/FB: C5.2, C6.2, R7.2, R8.1, U1.8 (FB), U5.6 (PW0)
/HB: C7.2, D1.1 (K), U1.18 (HB)
/HO: Q1.4 (G), U1.19 (HO)
/LO: Q2.4 (G), U1.15 (LO)
/SW: C7.1, L1.1, Q1.1 (S), Q1.2 (S), Q1.3 (S), Q2.5 (D), U1.20 (SW)
/VIN: C1.1, C2.1, C14.1, C24.1, J1.2, Q1.5 (D), R1.1, R4.1, R16.2, R17.2, U1.1 (VIN), U4.5 (VIN)
/VOUT: C9.2, C10.2, C11.2, C12.2, C13.2, C33.1, J2.2, L1.2, R7.1, R24.1, R26.1, U1.10 (VOUT)
ADC1: R24.2, R25.1, U2.10 (PA0)
ADC2: U2.11 (PA1)
ADC3: U2.12 (PA2)
ADC4: U2.13 (PA3)
CLK: J3.3, U2.37 (PA14)
DIO: J3.2, U2.34 (PA13)
GND: C1.2, C2.2, C3.2, C4.2, C8.1, C9.1, C10.1, C11.1, C12.1, C13.1, C14.2, C15.1, C16.1, C17.1, C18.2, C19.2, C20.2, C21.2, C22.2, C23.2, C24.2, C25.2, C26.2, C28.2, C29.2, C30.2, C31.1, C32.1, C33.2, D3.1 (Cathode), D4.1 (K), D5.1 (K), D6.1 (Cathode), D7.1 (K), J1.1, J2.1, J3.4, J4.A1 (GND), J4.A12 (GND), J4.B1 (GND), J4.B12 (GND), J4.S1 (SHIELD), J6.1, R2.2, R3.2, R6.2, R10.2, R19.2, R23.2, R25.2, SW1.1, SW2.2, SW3.2, SW4.2, SW5.2, U1.6 (AGND), U1.11 (DEMB), U1.13 (CSG), U1.14 (PGND), U1.17 (VCCX), U1.21 (DAP), U2.8 (VSSA), U2.23 (VSS), U2.35 (VSS), U2.47 (VSS), U3.3 (GND), U4.2 (GND), U5.4 (VSS), U6.2 (GND); also elsewhere on the board
MISO: U2.16 (PA6)
MOSI: U2.17 (PA7), U5.3 (SI)
NRST: C16.2, R9.2, SW1.2, U2.7 (NRST); also elsewhere on the board
unnamed: C3.1, U1.5 (RAMP)
unnamed: C4.1, U1.7 (SS)
unnamed: C6.1, R5.2
unnamed: C8.2, D1.2 (A), U1.16 (VCC)
unnamed: C27.1, L2.1, U4.6 (SW)
unnamed: C27.2, U4.1 (BST)
unnamed: D2.2 (A), R11.2
unnamed: D3.2 (Anode), R16.1
unnamed: D4.2 (A), R18.2
unnamed: D5.2 (A), R21.2
unnamed: D6.2 (Anode), R22.1
unnamed: D7.2 (A), R26.2
unnamed: Q2.1 (S), Q2.2 (S), Q2.3 (S), R6.1, U1.12 (CS)
unnamed: R1.2, R2.1, U1.2 (UVLO)
unnamed: R3.1, U1.3 (RT/SYNC)
unnamed: R4.2, U1.4 (EN)
unnamed: R10.1, U2.44 (BOOT0)
unnamed: R17.1, U4.4 (EN)
unnamed: R19.1, R20.2, U4.3 (FB)
PA8: D2.1 (K)
PB12/K1: C15.2, R12.2, SW2.1, U2.25 (PB12); also elsewhere on the board
PB13/K2: C17.2, R13.2, SW3.1, U2.26 (PB13); also elsewhere on the board
PB14/K3: C31.2, R14.2, SW4.1, U2.27 (PB14); also elsewhere on the board
PB15/K4: C32.2, R15.2, SW5.1, U2.28 (PB15); also elsewhere on the board
RCC_OSC_IN: U2.5 (PD0)
RCC_OSC_OUT: U2.6 (PD1)
RX: U2.43 (PB7), U3.8 (TXD)
SCK: U2.15 (PA5), U5.2 (SCK)
TX: U2.42 (PB6), U3.9 (RXD)
VCC: C18.1, C19.1, C20.1, C21.1, C22.1, C23.1, C25.1, C29.1, J3.1, J6.2, R9.1, R11.1, R12.1, R13.1, R14.1, R15.1, R18.1, R21.1, U2.1 (VBAT), U2.9 (VDDA), U2.24 (VDD), U2.36 (VDD), U2.48 (VDD), U3.7 (VCC), U3.10 (V3), U5.8 (VDD), U6.5 (VOUT)
i2C1_SCL: J6.3, U2.45 (PB8)
i2C1_SDA: J6.4, U2.46 (PB9)
~CS: U2.14 (PA4), U5.1 (~CS)

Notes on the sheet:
LDO
数字电位器
KEY
MCU
lm5116
OLED屏接口
辅助电源
USB2UART

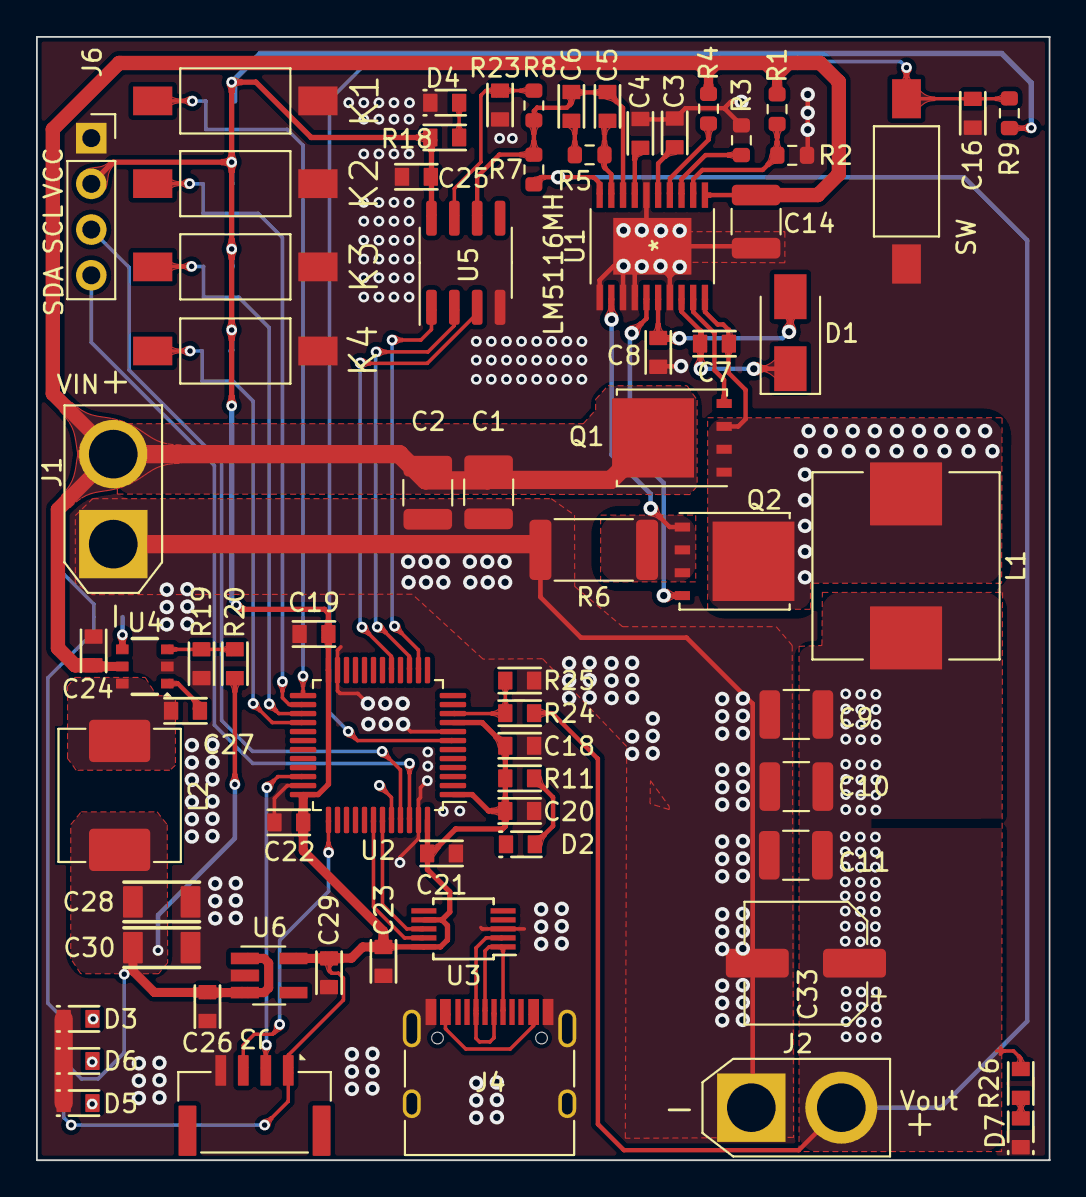
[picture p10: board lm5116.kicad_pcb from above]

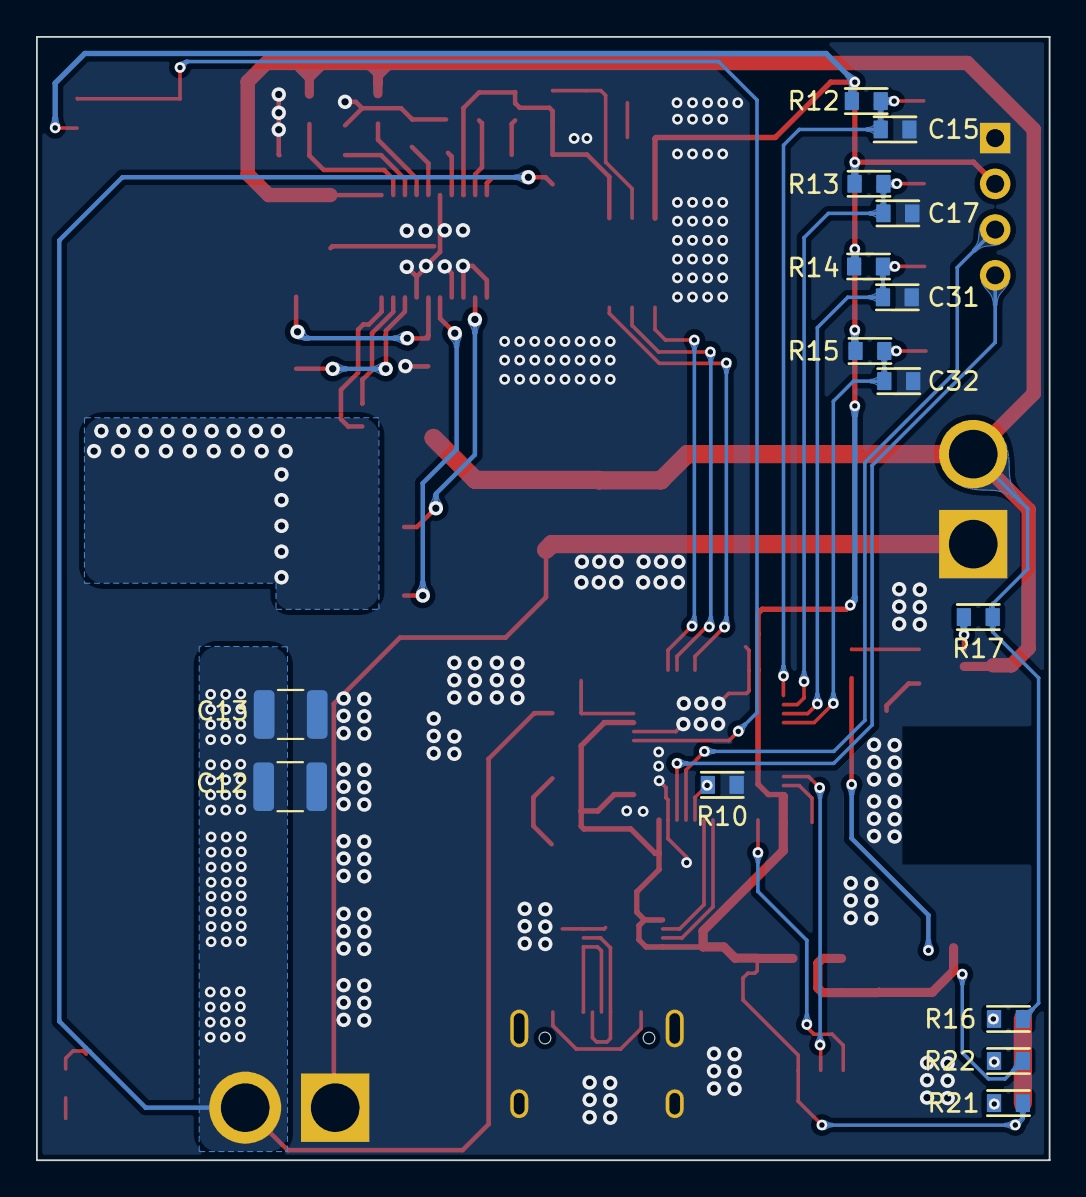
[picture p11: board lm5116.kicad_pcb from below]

Board: 2 copper layers, 56.3 x 62.4 mm, 86 parts (15 on the bottom side), 48 nets.

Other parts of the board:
K1, K2, K3, K4: SW_Push; SW_SPST_FSMSM
SW: SW_Push; SW_SPST_FSMSM

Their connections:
GND: K1.2, K2.2, K3.2, K4.2, SW.1; also elsewhere on the board
NRST: SW.2; also elsewhere on the board
PB12/K1: K1.1; also elsewhere on the board
PB13/K2: K2.1; also elsewhere on the board
PB14/K3: K3.1; also elsewhere on the board
PB15/K4: K4.1; also elsewhere on the board

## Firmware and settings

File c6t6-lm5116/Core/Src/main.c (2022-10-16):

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
/* Includes ------------------------------------------------------------------*/
#include "main.h"
#include "adc.h"
#include "dma.h"
#include "spi.h"
#include "usart.h"
#include "gpio.h"

/* USER CODE BEGIN Includes */
#include "mcp41100.h"
#include "delay.h"
#include"data_type_conversion.h"
#include "oled.h"
#include "printf.h"
#include "key.h"
#include "filter.h"
/* USER CODE END Includes */


/* USER CODE BEGIN PV */
extern uint8_t command;
extern uint8_t data;
extern volatile unsigned short adc_value[40];
extern uint8_t flag;
extern float avgerage_voltage;
extern float last_voltage;
/* USER CODE END PV */

void SystemClock_Config(void);
/**
  * @brief  The application entry point.
  * @retval int
  */
int main(void) {
    /* MCU Configuration--------------------------------------------------------*/

    /* Reset of all peripherals, Initializes the Flash interface and the Systick. */
    HAL_Init();

    /* Configure the system clock */
    SystemClock_Config();

    /* Initialize all configured peripherals */
    MX_GPIO_Init();
    MX_DMA_Init();
    MX_ADC1_Init();
    MX_SPI1_Init();
    MX_USART1_UART_Init();
    /* USER CODE BEGIN 2 */
    HAL_ADCEx_Calibration_Start(&hadc1);

    OLED_Init();//初始化OLED
    OLED_Fill(0X00);//清屏
    //数字电位器的指令
    data = 0B01111111;
    uint8_t key_flag = 0;
    float expect_voltage = 5;
    char V_string[10] = {'0'};
    HAL_UART_Transmit(&huart1, "start\r\n", 7, HAL_MAX_DELAY);
    /* USER CODE END 2 */
    /* Infinite loop */
    /* USER CODE BEGIN WHILE */
    HAL_ADC_Start_DMA(&hadc1, (uint32_t *) adc_value, 40);

    while (1) {
        /* USER CODE END WHILE */

        /* USER CODE BEGIN 3 */


        MCP41100_Send_Data(MCP41100_ENABLE, data);
        //通过按键控制电压
        key_flag = Enter_Key();
        if (key_flag == VOLTAGE_UP) {
            data--;
        } else if (key_flag == VOLTAGE_DOWN) {
            data++;
        }
        //采样并显示
        if (flag) {
            OLED_ShowMenu(expect_voltage, avgerage_voltage * 0.004833f);
            flag = 0;
        }
        HAL_Delay(10);


    }
    /* USER CODE END 3 */
}

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


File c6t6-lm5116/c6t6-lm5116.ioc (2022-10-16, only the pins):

Mcu.UserName=STM32F103C6Tx
PA0-WKUP.Signal=ADCx_IN0
PA13.Signal=SYS_JTMS-SWDIO
PA14.Signal=SYS_JTCK-SWCLK
PA4.GPIO_Label=CS
PA4.Signal=GPIO_Output
PA5.Signal=SPI1_SCK
PA6.Signal=SPI1_MISO
PA7.Signal=SPI1_MOSI
PA8.GPIO_Label=LED
PA8.Signal=GPIO_Output
PB12.GPIO_Label=K1
PB12.Signal=GPIO_Input
PB13.GPIO_Label=K2
PB13.Signal=GPIO_Input
PB14.GPIO_Label=K3
PB14.Signal=GPIO_Input
PB15.GPIO_Label=K4
PB15.Signal=GPIO_Input
PB6.Signal=USART1_TX
PB7.Signal=USART1_RX
PB8.GPIO_Label=SCL
PB8.Signal=GPIO_Output
PB9.GPIO_Label=SDA
PB9.Signal=GPIO_Output
PD0-OSC_IN.Signal=RCC_OSC_IN
PD1-OSC_OUT.Signal=RCC_OSC_OUT

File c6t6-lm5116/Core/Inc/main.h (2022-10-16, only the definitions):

#define CS_Pin GPIO_PIN_4
#define CS_GPIO_Port GPIOA
#define K1_Pin GPIO_PIN_12
#define K1_GPIO_Port GPIOB
#define K2_Pin GPIO_PIN_13
#define K2_GPIO_Port GPIOB
#define K3_Pin GPIO_PIN_14
#define K3_GPIO_Port GPIOB
#define K4_Pin GPIO_PIN_15
#define K4_GPIO_Port GPIOB
#define LED_Pin GPIO_PIN_8
#define LED_GPIO_Port GPIOA
#define SCL_Pin GPIO_PIN_8
#define SCL_GPIO_Port GPIOB
#define SDA_Pin GPIO_PIN_9
#define SDA_GPIO_Port GPIOB

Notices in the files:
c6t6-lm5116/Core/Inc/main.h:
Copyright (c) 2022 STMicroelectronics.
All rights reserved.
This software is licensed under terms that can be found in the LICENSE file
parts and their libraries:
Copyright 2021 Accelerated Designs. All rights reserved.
